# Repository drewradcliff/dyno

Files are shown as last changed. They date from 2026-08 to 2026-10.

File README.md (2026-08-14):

# Dyno

Dyno is an open-source finger-strength dynamometer. The project combines a
custom load-cell PCB, firmware for a Seeed Studio XIAO ESP32C3, and a mobile
app that displays force measurements over Bluetooth Low Energy.

## Repository

- [`hardware/`](hardware/) — KiCad schematic, PCB, and project-local libraries
- [`firmware/`](firmware/) — ESP32C3 firmware, calibration, and telemetry
- [`mobile/`](mobile/) — Expo/React Native companion app

The project is under active development. The PCB is currently an unverified
prototype and should be reviewed before fabrication.

## License

Original project work is licensed under the [MIT License](LICENSE). Third-party
components retain their upstream licenses and are attributed in the relevant
component directories.

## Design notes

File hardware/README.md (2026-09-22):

# Dyno hardware

KiCad design for the battery-powered Dyno finger-strength sensor. The board
combines a Seeed Studio XIAO ESP32C3 with an HX711 ADC and an external load
cell.

> **Status:** early, unverified prototype. The schematic and PCB have not yet
> been validated on manufactured hardware.

The [`production`](production) directory contains the JLCPCB Gerbers, BOM, and
placement data generated by KiCad's Fabrication Toolkit.

## Open the project

Open [`dyno.kicad_pro`](dyno.kicad_pro) with KiCad 10 or newer.

## Attribution and licensing

The original Dyno hardware design is licensed under the repository's
[MIT License](../LICENSE).

The vendored Seeed Studio XIAO KiCad libraries were created by Seeed Studio and
community contributors and are licensed separately under CC BY-SA 4.0. See
[`libraries/README.md`](libraries/README.md) and
[`libraries/LICENSE-CC-BY-SA-4.0.md`](libraries/LICENSE-CC-BY-SA-4.0.md).

The design also uses symbols and footprints from the official KiCad libraries,
which are distributed under CC BY-SA 4.0 with the KiCad libraries exception.
That exception permits their use in electronic designs without requiring the
design itself to adopt CC BY-SA.

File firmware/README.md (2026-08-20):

# Dyno firmware

Arduino firmware for the Seeed Studio XIAO ESP32C3. It reads an HX711 load-cell
ADC, calculates force, detects completed efforts, and publishes measurements
over serial and Bluetooth Low Energy.

## Setup

Install the ESP32 Arduino core and the
[HX711 library by bogde](https://github.com/bogde/HX711), then open
[`dyno/dyno.ino`](dyno/dyno.ino) in the Arduino IDE.

The HX711 connections expected by the firmware are:

- `D1`: active-low sleep/wake button
- `D3`: active-high status LED
- `D4`: HX711 `DOUT`
- `D5`: HX711 `PD_SCK`

The status LED is off while the dyno is idle, solid while an effort is active,
and blinks every 500 ms if the HX711 is not detected at startup.

## Sleep and wake button

The schematic's R2 pulls XIAO `D1` (GPIO 3) high, and SW1 connects it to ground
when pressed. Hold SW1 for two seconds and then release it to enter deep sleep.
Releasing before sleep prevents the active-low wake source from immediately
waking the board again. Press SW1 once while the board is asleep to wake it.

After a button wake, the firmware waits for SW1 to be released before arming
the hold-to-sleep behavior. This prevents a long wake press from creating a
sleep/wake loop. Deep sleep can also be requested with the `sleep` serial or
BLE command; if SW1 is held, sleep begins when it is released.

## BLE

The XIAO advertises as `Dyno` with an open GATT service. Connecting does not
require pairing or bonding.

| Item | UUID | Properties | Value |
| --- | --- | --- | --- |
| Dyno service | `7b7e1000-6ba3-4d8f-9e2f-4f2f0c7a0000` | — | — |
| Force | `7b7e1001-6ba3-4d8f-9e2f-4f2f0c7a0000` | Read, Notify | UTF-8 newtons with three decimal places, such as `12.345` |
| Command | `7b7e1002-6ba3-4d8f-9e2f-4f2f0c7a0000` | Write, Write Without Response | UTF-8 command, with or without a trailing newline |

Force notifications contain the latest filtered reading and are limited to
40 updates per second.

## Serial output

Open the serial port at 115200 baud. Each available HX711 conversion is read
once, timestamped, low-pass filtered, and emitted as CSV:

```csv
timestamp_ms,raw,force_newtons
1250,25802,0.406
1263,26143,8.104
1275,26994,27.314
```

Lines beginning with `#` are status messages or effort events. The `raw`
column is the unmodified HX711 reading; `force_newtons` is calculated from the
tared, filtered reading.

## Tare and calibration

At startup, the device collects 16 unloaded samples to establish its tare.
Keep the load cell unloaded until `# tare_complete` appears. Available serial
commands are:

```text
tare
factor 1461.258
calibrate 98.0665
thresholds 20 10 1000
last
status
sleep
help
```

- `tare` starts a fresh 16-sample unloaded tare.
- `factor <counts_per_newton>` sets the signed calibration factor.
- `calibrate <known_newtons>` calculates the factor from the currently applied
  force after an unloaded tare.
- `thresholds <start_n> <end_n> <hold_ms>` configures effort detection. The
  start threshold must be greater than the end threshold.
- `last` reports the most recently completed effort.
- `status` reports calibration, effort state, peak, and thresholds.
- `sleep` enters deep sleep with SW1 on `D1` configured as the active-low wake
  source.

Calibration and threshold settings persist in ESP32 flash. The default factor
converts the initial bench calibration of 6500 counts per pound-force:

```text
6500 counts/lbf / 4.448221615 N/lbf = 1461.258 counts/N
```

A negative calibration factor is valid when the raw reading falls as force is
applied.

## Efforts and peak force

An effort begins when filtered force rises above 20 N. The firmware tracks its
peak and ends it after force remains below 10 N for one second. This hysteresis
prevents small fluctuations from prematurely ending an effort.

Every completed effort records its ID, timestamps, duration, and peak force.
The last result remains available through `last` until restart. Taring,
calibrating, or changing thresholds during an effort cancels that partial
effort.

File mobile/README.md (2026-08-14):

# Dyno mobile

Expo/React Native companion app for the Dyno force sensor. It discovers the
device over Bluetooth Low Energy, reconnects to known devices, and displays
live force measurements.

## Development

```bash
npm install
npx expo run:ios
```

Use `npx expo run:android` for Android. BLE requires a development build and a
physical device; it is not available in Expo Go or a typical simulator.

After installing the development build, start Metro with:

```bash
npm start
```

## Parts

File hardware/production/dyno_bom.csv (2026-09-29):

Designator | Footprint | Quantity | Value | LCSC Part #
C1, C2, C5, C6, C7 | 0603 | 5 | 100n | C14663
C3, C4 | 0805 | 2 | 10u | C15850
D1 | 0603 | 1 | LED | C2286
J1 | JST_PH_S2B-PH-SM4-TB_1x02-1MP_P2.00mm_Horizontal | 1 | Battery | C295747
J2 | JST_SH_SM04B-SRSS-TB_1x04-1MP_P1.00mm_Horizontal | 1 | Load cell (4-wire) | C160404
Q1 | SOT-23 | 1 | MMBT3906LT1G | C53444
R1 | 0603 | 1 | 100k | C25803
R2, R4 | 0603 | 2 | 10k | C25804
R3 | 0603 | 1 | 14k | C22803
R5, R6 | 0603 | 2 | 100 | C22775
R7 | 0603 | 1 | 2.2k | C4190
SW1 | SW_SPST_B3U-1000P | 1 | B3U-1000P | C231329
U1 | XIAO-ESP32-C3-SMD | 1 | XIAO-ESP32-C3-SMD | C18212168
U2 | SOIC-16_3.9x9.9mm_P1.27mm | 1 | HX711 | C6705483

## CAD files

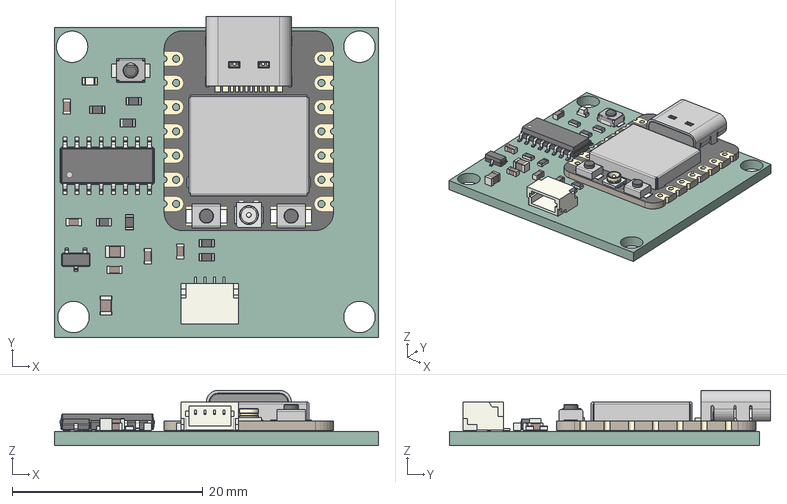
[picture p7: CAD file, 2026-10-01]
hardware/dyno-fusion-usb.step
34.0 x 33.7 x 5.80 mm
R_0603_1608Metric x 7
LED_0603_1608Metric
C_0603_1608Metric x 5
C_0805_2012Metric x 2
SOIC-16_3.9x9.9mm_P1.27mm
BOSS-EXTRUDE14_8_
BOSS-EXTRUDE7_4_
BOSS-EXTRUDE7_3_
BOSS-EXTRUDE14_4_
BOSS-EXTRUDE14_2_
BOSS-EXTRUDE14_11_
BOSS-EXTRUDE7_7_
BOSS-EXTRUDE14_9_
BOSS-EXTRUDE14_3_
BOSS-EXTRUDE14_7_
MIRROR2
BOSS-EXTRUDE14_5_
BOSS-EXTRUDE14_12_
BOSS-EXTRUDE7_8_
BOSS-EXTRUDE7_1_
BOSS-EXTRUDE14_10_
BOSS-EXTRUDE7_9_
BOSS-EXTRUDE14_6_
BOSS-EXTRUDE14_1_
BOSS-EXTRUDE7_6_
BOSS-EXTRUDE7_2_
CUT-EXTRUDE5
BOSS-EXTRUDE7_5_
U.FL Connector v1
Button (1) x 2
Shield
JST_SH_SM04B-SRSS-TB_1x04-1MP_P1.00mm_Horizontal
SOT-23
SW_SPST_B3U-1000P
dyno_PCB

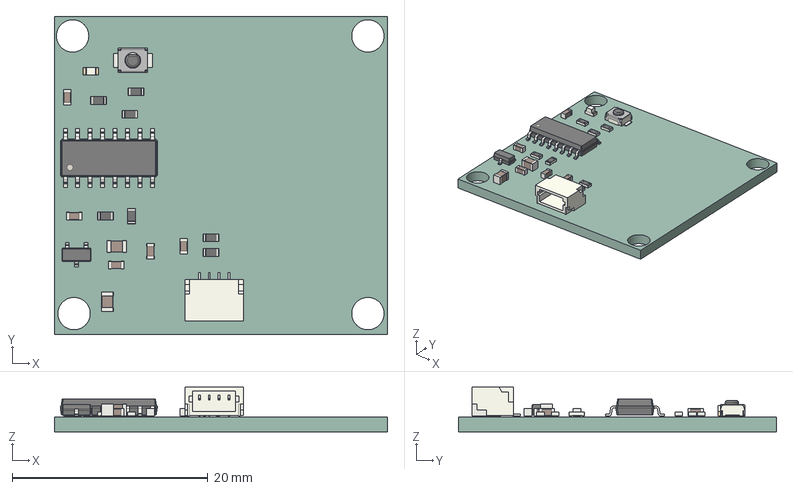
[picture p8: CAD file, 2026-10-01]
hardware/dyno-fusion.step
34.0 x 32.5 x 4.55 mm
R_0603_1608Metric x 7
LED_0603_1608Metric
C_0603_1608Metric x 5
C_0805_2012Metric x 2
SOIC-16_3.9x9.9mm_P1.27mm
JST_SH_SM04B-SRSS-TB_1x04-1MP_P1.00mm_Horizontal
SOT-23
SW_SPST_B3U-1000P
dyno-unsaved-export-k7dwvz_PCB

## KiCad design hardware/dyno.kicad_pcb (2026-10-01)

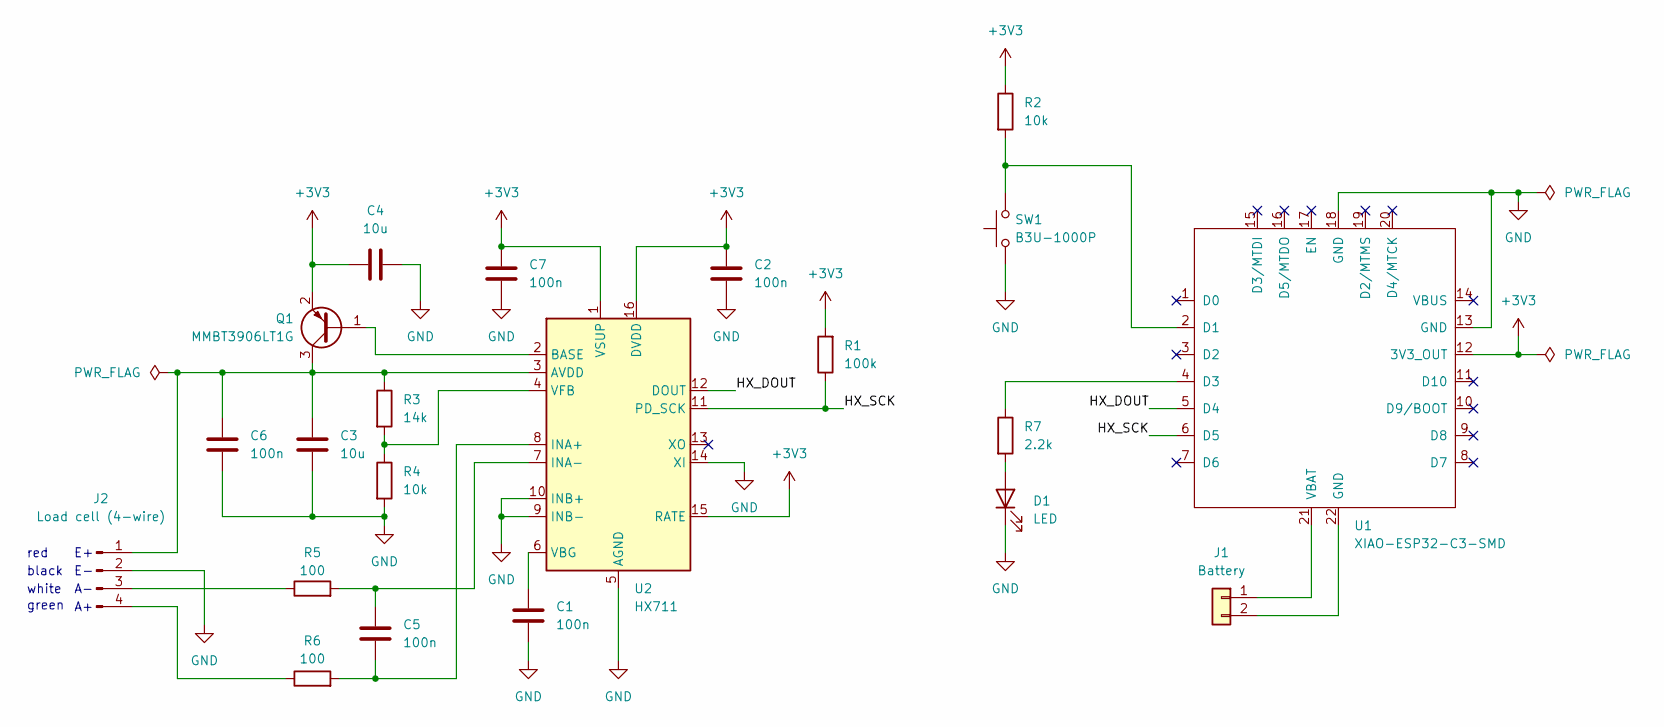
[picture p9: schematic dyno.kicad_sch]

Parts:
C1, C2, C5, C6, C7: 100n; C_0603_1608Metric; MPN CC0603KRX7R9BB104; JLCPCB Part # C14663
C3, C4: 10u; C_0805_2012Metric; MPN CL21A106KAYNNNE; JLCPCB Part # C15850
D1: LED; LED_0603_1608Metric; MPN KT-0603R; JLCPCB Part # C2286
J1: Battery; JST_PH_S2B-PH-SM4-TB_1x02-1MP_P2.00mm_Horizontal; MPN S2B-PH-SM4-TB(LF)(SN); JLCPCB Part # C295747
J2: Load cell (4-wire); JST_SH_SM04B-SRSS-TB_1x04-1MP_P1.00mm_Horizontal; MPN SM04B-SRSS-TB(LF)(SN); JLCPCB Part # C160404
Q1: MMBT3906LT1G; SOT-23; MPN MMBT3906LT1G; JLCPCB Part # C53444
R1: 100k; R_0603_1608Metric; MPN 0603WAF1003T5E; JLCPCB Part # C25803
R2, R4: 10k; R_0603_1608Metric; MPN 0603WAF1002T5E; JLCPCB Part # C25804
R3: 14k; R_0603_1608Metric; MPN 0603WAF1402T5E; JLCPCB Part # C22803
R5, R6: 100; R_0603_1608Metric; MPN 0603WAF1000T5E; JLCPCB Part # C22775
R7: 2.2k; R_0603_1608Metric; MPN 0603WAF2201T5E; JLCPCB Part # C4190
SW1: B3U-1000P; SW_SPST_B3U-1000P; MPN B3U-1000P; JLCPCB Part # C231329
U1: XIAO-ESP32-C3-SMD; MPN 113991054; JLCPCB Part # C18212168
U2: HX711; SOIC-16_3.9x9.9mm_P1.27mm; MPN HX711; JLCPCB Part # C6705483

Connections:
+3V3: C2.2, C4.1, C7.2, Q1.2 (E), R1.2, R2.1, U1.12 (3V3_OUT), U2.1 (VSUP), U2.15 (RATE), U2.16 (DVDD)
/HX_DOUT: U1.5 (D4), U2.12 (DOUT)
/HX_SCK: R1.1, U1.6 (D5), U2.11 (PD_SCK)
GND: C1.2, C2.1, C3.2, C4.2, C6.2, C7.1, D1.1 (K), J2.2, R4.2, SW1.1, U1.13 (GND), U1.18 (GND), U2.5 (AGND), U2.9 (INB-), U2.10 (INB+), U2.14 (XI)
unnamed: D1.2 (A), R7.2
unnamed: J1.1, U1.21 (VBAT)
unnamed: J1.2, U1.22 (GND)
unnamed: C3.1, C6.1, J2.1, Q1.3 (C), R3.1, U2.3 (AVDD)
unnamed: J2.3, R5.1
unnamed: J2.4, R6.1
unnamed: Q1.1 (B), U2.2 (BASE)
unnamed: R2.2, SW1.2, U1.2 (D1)
unnamed: R7.1, U1.4 (D3)
unnamed: C5.2, R6.2, U2.8 (INA+)
unnamed: C5.1, R5.2, U2.7 (INA-)
unnamed: C1.1, U2.6 (VBG)
unnamed: R3.2, R4.1, U2.4 (VFB)

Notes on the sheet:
green
red
white
black

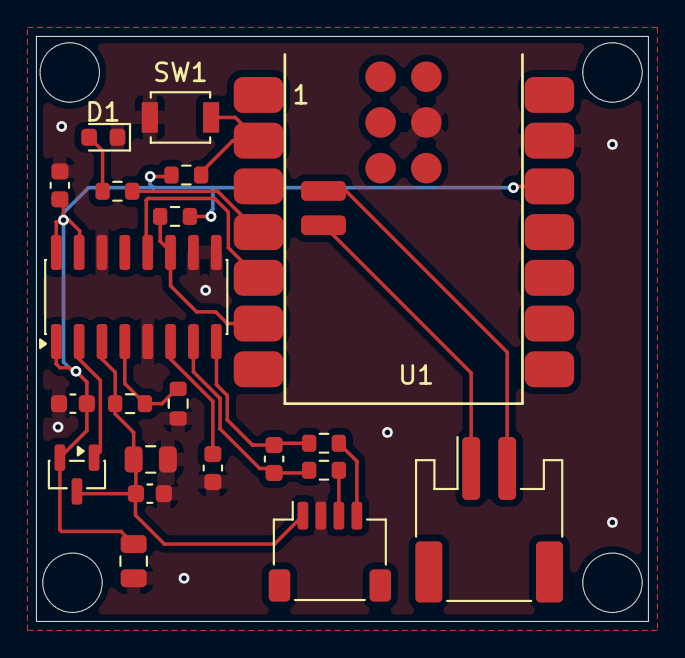
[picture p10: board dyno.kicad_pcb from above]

Board: 2 copper layers, 34.0 x 32.5 mm, 21 parts (0 on the bottom side), 17 nets.

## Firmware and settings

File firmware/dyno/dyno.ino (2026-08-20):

#include <Arduino.h>
#include <Preferences.h>
#include <esp_sleep.h>

#include <ctype.h>
#include <limits.h>
#include <math.h>
#include <stdlib.h>
#include <string.h>

#include "BleTelemetry.h"
#include "DynoTypes.h"
#include "EffortDetector.h"
#include "HX711.h"
#include "SerialTelemetry.h"

constexpr int HX711_DOUT_PIN = D4;
constexpr int HX711_SCK_PIN = D5;
constexpr int WAKE_BUTTON_PIN = D1;
constexpr int STATUS_LED_PIN = D3;

// R2 holds D1 high and SW1 pulls it low. Requiring a hold avoids putting the
// dyno to sleep during an accidental tap; sleep begins after the button is
// released so the same low level cannot immediately wake it again.
constexpr uint32_t WAKE_BUTTON_DEBOUNCE_MS = 30;
constexpr uint32_t WAKE_BUTTON_SLEEP_HOLD_MS = 2000;
constexpr uint32_t STATUS_LED_BLINK_INTERVAL_MS = 500;

// A positive factor means raw count rises with applied force. Use a negative
// factor if it falls. Serial calibration commands are persisted in flash.
constexpr float DEFAULT_CALIBRATION_FACTOR_COUNTS_PER_NEWTON = 1461.258f;
constexpr dyno::EffortConfig DEFAULT_EFFORT_CONFIG = {20.0f, 10.0f, 1000};

constexpr uint8_t TARE_SAMPLE_COUNT = 16;
constexpr float FILTER_ALPHA = 0.20f;
constexpr size_t COMMAND_BUFFER_SIZE = 96;

HX711 loadcell;
Preferences preferences;
SerialTelemetry serialTelemetry;
BleTelemetry bleTelemetry;
dyno::EffortDetector effortDetector(DEFAULT_EFFORT_CONFIG);

bool hx711Initialized = false;
bool hx711Detected = false;
bool preferencesReady = false;
bool statusError = false;
float calibrationFactor = DEFAULT_CALIBRATION_FACTOR_COUNTS_PER_NEWTON;
long tareOffset = 0;

bool tareInProgress = false;
uint8_t tareSamplesCollected = 0;
int64_t tareAccumulator = 0;

bool filterInitialized = false;
float filteredCounts = 0.0f;
bool hasMeasurement = false;
uint32_t nextSampleSequence = 0;

bool wakeButtonRawPressed = false;
bool wakeButtonStablePressed = false;
bool wakeButtonArmed = false;
bool sleepWhenWakeButtonReleased = false;
uint32_t wakeButtonRawChangedAtMs = 0;
uint32_t wakeButtonPressedAtMs = 0;

char commandBuffer[COMMAND_BUFFER_SIZE];
size_t commandLength = 0;
bool discardCommandUntilNewline = false;

void initializeStatusLed() {
  pinMode(STATUS_LED_PIN, OUTPUT);
  digitalWrite(STATUS_LED_PIN, LOW);
}

void updateStatusLed() {
  bool ledOn = effortDetector.active();
  if (statusError) {
    ledOn = (millis() / STATUS_LED_BLINK_INTERVAL_MS) % 2 == 0;
  }

  digitalWrite(STATUS_LED_PIN, ledOn ? HIGH : LOW);
}

void publishMeasurement(const dyno::ForceMeasurement &measurement) {
  serialTelemetry.publishMeasurement(measurement);
  bleTelemetry.publishMeasurement(measurement);
}

void publishEffortEvent(const dyno::EffortEvent &event) {
  serialTelemetry.publishEffortEvent(event);
}

void cancelActiveEffort() {
  publishEffortEvent(effortDetector.cancel(millis()));
}

void printWakeCause() {
  const esp_sleep_wakeup_cause_t wakeCause = esp_sleep_get_wakeup_cause();
  if (wakeCause == ESP_SLEEP_WAKEUP_GPIO) {
    Serial.println(F("# wake_cause=button"));
  } else {
    Serial.print(F("# wake_cause="));
    Serial.println(static_cast<int>(wakeCause));
  }
}

void enterDeepSleep() {
  cancelActiveEffort();
  digitalWrite(STATUS_LED_PIN, LOW);
  if (hx711Initialized) {
    loadcell.power_down();
  }
  if (preferencesReady) {
    preferences.end();
    preferencesReady = false;
  }

  const esp_err_t wakeResult = esp_deep_sleep_enable_gpio_wakeup(
      1ULL << WAKE_BUTTON_PIN, ESP_GPIO_WAKEUP_GPIO_LOW);
  if (wakeResult != ESP_OK) {
    Serial.print(F("# error,wake_button_config_failed="));
    Serial.println(esp_err_to_name(wakeResult));
    Serial.flush();
    delay(1000);
    ESP.restart();
  }

  Serial.println(F("# deep_sleep,wake_source=D1,active_level=low"));
  Serial.flush();
  delay(20);
  esp_deep_sleep_start();

  // esp_deep_sleep_start() does not return; keep the compiler aware of that.
  while (true) {
  }
}

void initializeWakeButton() {
  // The schematic includes an external 10 kOhm pull-up (R2). INPUT_PULLUP also
  // keeps the input defined if R2 is omitted during breadboard testing.
  pinMode(WAKE_BUTTON_PIN, INPUT_PULLUP);
  wakeButtonRawPressed = digitalRead(WAKE_BUTTON_PIN) == LOW;
  wakeButtonStablePressed = wakeButtonRawPressed;
  wakeButtonRawChangedAtMs = millis();
  wakeButtonPressedAtMs = millis();

  // A button still held after waking must be released before it can request
  // sleep. Otherwise a long wake press would cause a sleep/wake loop.
  wakeButtonArmed = !wakeButtonStablePressed;
}

void pollWakeButton() {
  const uint32_t nowMs = millis();
  const bool rawPressed = digitalRead(WAKE_BUTTON_PIN) == LOW;

  if (rawPressed != wakeButtonRawPressed) {
    wakeButtonRawPressed = rawPressed;
    wakeButtonRawChangedAtMs = nowMs;
  }

  if (wakeButtonStablePressed != wakeButtonRawPressed &&
      nowMs - wakeButtonRawChangedAtMs >= WAKE_BUTTON_DEBOUNCE_MS) {
    wakeButtonStablePressed = wakeButtonRawPressed;
    if (wakeButtonStablePressed) {
      if (wakeButtonArmed) {
        wakeButtonPressedAtMs = nowMs;
      }
    } else {
      wakeButtonArmed = true;
      if (sleepWhenWakeButtonReleased) {
        enterDeepSleep();
      }
    }
  }

  if (wakeButtonArmed && wakeButtonStablePressed &&
      !sleepWhenWakeButtonReleased &&
      nowMs - wakeButtonPressedAtMs >= WAKE_BUTTON_SLEEP_HOLD_MS) {
    sleepWhenWakeButtonReleased = true;
    Serial.println(F("# sleep_requested,release_button_to_sleep"));
  }
}

void beginTare() {
  cancelActiveEffort();
  tareInProgress = true;
  tareSamplesCollected = 0;
  tareAccumulator = 0;
  filterInitialized = false;
  hasMeasurement = false;
  Serial.println(F("# tare_start"));
}

void collectTareSample(long raw) {
  tareAccumulator += raw;
  ++tareSamplesCollected;

  if (tareSamplesCollected < TARE_SAMPLE_COUNT) {
    return;
  }

  tareOffset = static_cast<long>(tareAccumulator / TARE_SAMPLE_COUNT);
  tareInProgress = false;

  Serial.print(F("# tare_complete,offset="));
  Serial.println(tareOffset);
}

void persistCalibrationFactor() {
  if (preferencesReady) {
    preferences.putFloat("factor", calibrationFactor);
  }
}

void persistEffortConfig() {
  if (!preferencesReady) {
    return;
  }

  const dyno::EffortConfig &config = effortDetector.config();
  preferences.putFloat("start_n", config.startForceNewtons);
  preferences.putFloat("end_n", config.endForceNewtons);
  preferences.putUInt("hold_ms", config.endHoldMs);
}

void printCalibrationFactor() {
  Serial.print(F("# calibration_factor_counts_per_newton="));
  Serial.println(calibrationFactor, 6);
}

void printEffortConfig() {
  const dyno::EffortConfig &config = effortDetector.config();
  Serial.print(F("# effort_config,start_force_newtons="));
  Serial.print(config.startForceNewtons, 3);
  Serial.print(F(",end_force_newtons="));
  Serial.print(config.endForceNewtons, 3);
  Serial.print(F(",end_hold_ms="));
  Serial.println(config.endHoldMs);
}

void printHelp() {
  Serial.println(F("# commands: tare | factor <counts_per_newton> | calibrate <known_newtons> | thresholds <start_n> <end_n> <hold_ms> | last | status | sleep | help"));
}

void printLastEffort() {
  if (!effortDetector.hasLastCompletedEffort()) {
    Serial.println(F("# last_effort,none"));
    return;
  }

  serialTelemetry.publishLastEffort(effortDetector.lastCompletedEffort());
}

void printStatus() {
  const dyno::EffortConfig &config = effortDetector.config();
  Serial.print(F("# status,tare_offset="));
  Serial.print(tareOffset);
  Serial.print(F(",calibration_factor_counts_per_newton="));
  Serial.print(calibrationFactor, 6);
  Serial.print(F(",effort_active="));
  Serial.print(effortDetector.active() ? 1 : 0);
  Serial.print(F(",effort_id="));
  Serial.print(effortDetector.currentEffortId());
  Serial.print(F(",current_peak_force_newtons="));
  Serial.print(effortDetector.currentPeakForceNewtons(), 3);
  Serial.print(F(",start_force_newtons="));
  Serial.print(config.startForceNewtons, 3);
  Serial.print(F(",end_force_newtons="));
  Serial.print(config.endForceNewtons, 3);
  Serial.print(F(",end_hold_ms="));
  Serial.println(config.endHoldMs);
}

void skipWhitespace(const char *&cursor) {
  while (isspace(static_cast<unsigned char>(*cursor))) {
    ++cursor;
  }
}

bool parseFloatToken(const char *&cursor, float &value) {
  if (cursor == nullptr) {
    return false;
  }

  skipWhitespace(cursor);
  char *end = nullptr;
  value = strtof(cursor, &end);
  if (end == cursor || !isfinite(value)) {
    return false;
  }

  cursor = end;
  return true;
}

bool parseUInt32Token(const char *&cursor, uint32_t &value) {
  if (cursor == nullptr) {
    return false;
  }

  skipWhitespace(cursor);
  if (*cursor == '-') {
    return false;
  }

  char *end = nullptr;
  const unsigned long parsed = strtoul(cursor, &end, 10);
  if (end == cursor || parsed > UINT32_MAX) {
    return false;
  }

  value = static_cast<uint32_t>(parsed);
  cursor = end;
  return true;
}

bool isEndOfArguments(const char *cursor) {
  if (cursor == nullptr) {
    return true;
  }

  skipWhitespace(cursor);
  return *cursor == '\0';
}

bool parseSingleFloatArgument(const char *argument, float &value) {
  return parseFloatToken(argument, value) && isEndOfArguments(argument);
}

bool parseEffortConfig(const char *argument, dyno::EffortConfig &config) {
  return parseFloatToken(argument, config.startForceNewtons) &&
         parseFloatToken(argument, config.endForceNewtons) &&
         parseUInt32Token(argument, config.endHoldMs) &&
         isEndOfArguments(argument) &&
         dyno::EffortDetector::isValidConfig(config);
}

void applyCalibrationFactor(float newFactor) {
  cancelActiveEffort();
  calibrationFactor = newFactor;
  persistCalibrationFactor();
  printCalibrationFactor();
}

void applyEffortConfig(const dyno::EffortConfig &config) {
  cancelActiveEffort();
  effortDetector.setConfig(config);
  persistEffortConfig();
  printEffortConfig();
}

void handleCommand(char *command) {
  while (isspace(static_cast<unsigned char>(*command))) {
    ++command;
  }

  char *commandEnd = command + strlen(command);
  while (commandEnd > command &&
         isspace(static_cast<unsigned char>(commandEnd[-1]))) {
    --commandEnd;
  }
  *commandEnd = '\0';

  if (*command == '\0') {
    return;
  }

  char *argument = command;
  while (*argument != '\0' &&
         !isspace(static_cast<unsigned char>(*argument))) {
    ++argument;
  }
  if (*argument != '\0') {
    *argument = '\0';
    ++argument;
  } else {
    argument = nullptr;
  }

  if (strcmp(command, "tare") == 0) {
    if (!hx711Detected) {
      Serial.println(F("# error,hx711_not_detected"));
      return;
    }

    beginTare();
    return;
  }

  if (strcmp(command, "factor") == 0) {
    float requestedFactor = 0.0f;
    if (!parseSingleFloatArgument(argument, requestedFactor) ||
        fabsf(requestedFactor) < 0.000001f) {
      Serial.println(
          F("# error,usage=factor <non-zero counts_per_newton>"));
      return;
    }

    applyCalibrationFactor(requestedFactor);
    return;
  }

  if (strcmp(command, "calibrate") == 0) {
    float knownForceNewtons = 0.0f;
    if (!parseSingleFloatArgument(argument, knownForceNewtons) ||
        knownForceNewtons <= 0.0f) {
      Serial.println(
          F("# error,usage=calibrate <positive_known_newtons>"));
      return;
    }

    if (!hasMeasurement || fabsf(filteredCounts) < 1.0f) {
      Serial.println(F("# error,apply_known_force_before_calibrating"));
      return;
    }

    applyCalibrationFactor(filteredCounts / knownForceNewtons);
    return;
  }

  if (strcmp(command, "thresholds") == 0) {
    dyno::EffortConfig config = DEFAULT_EFFORT_CONFIG;
    if (!parseEffortConfig(argument, config)) {
      Serial.println(
          F("# error,usage=thresholds <start_n> <end_n> <hold_ms>; start_n must be greater than end_n"));
      return;
    }

    applyEffortConfig(config);
    return;
  }

  if (strcmp(command, "last") == 0) {
    printLastEffort();
    return;
  }

  if (strcmp(command, "status") == 0) {
    printStatus();
    return;
  }

  if (strcmp(command, "sleep") == 0) {
    if (digitalRead(WAKE_BUTTON_PIN) == LOW) {
      sleepWhenWakeButtonReleased = true;
      Serial.println(F("# sleep_requested,release_button_to_sleep"));
    } else {
      enterDeepSleep();
    }
    return;
  }

  if (strcmp(command, "help") == 0) {
    printHelp();
    return;
  }

  Serial.println(F("# error,unknown_command"));
  printHelp();
}

void readSerialCommands() {
  while (Serial.available() > 0) {
    const char nextCharacter = static_cast<char>(Serial.read());

    if (nextCharacter == '\r') {
      continue;
    }

    if (nextCharacter == '\n') {
      if (discardCommandUntilNewline) {
        discardCommandUntilNewline = false;
        commandLength = 0;
        continue;
      }

      commandBuffer[commandLength] = '\0';
      handleCommand(commandBuffer);
      commandLength = 0;
      continue;
    }

    if (discardCommandUntilNewline) {
      continue;
    }

    if (commandLength < COMMAND_BUFFER_SIZE - 1) {
      commandBuffer[commandLength++] = nextCharacter;
    } else {
      commandLength = 0;
      discardCommandUntilNewline = true;
      Serial.println(F("# error,command_too_long"));
    }
  }
}

void readBleCommands() {
  char command[COMMAND_BUFFER_SIZE];
  if (bleTelemetry.takeCommand(command, sizeof(command))) {
    handleCommand(command);
  }
}

void processSample(long raw, uint32_t timestampMs) {
  const float netCounts = static_cast<float>(raw - tareOffset);

  if (!filterInitialized) {
    filteredCounts = netCounts;
    filterInitialized = true;
  } else {
    filteredCounts += FILTER_ALPHA * (netCounts - filteredCounts);
  }

  hasMeasurement = true;
  const float forceNewtons = filteredCounts / calibrationFactor;
  publishEffortEvent(effortDetector.update(forceNewtons, timestampMs));

  const dyno::ForceMeasurement measurement = {
      nextSampleSequence++,
      timestampMs,
      static_cast<int32_t>(raw),
      forceNewtons,
      effortDetector.currentEffortId(),
      effortDetector.active(),
  };
  publishMeasurement(measurement);
}

void loadPersistentSettings() {
  preferencesReady = preferences.begin("dyno", false);
  if (!preferencesReady) {
    return;
  }

  const float storedFactor = preferences.getFloat(
      "factor", DEFAULT_CALIBRATION_FACTOR_COUNTS_PER_NEWTON);
  if (isfinite(storedFactor) && fabsf(storedFactor) >= 0.000001f) {
    calibrationFactor = storedFactor;
  }

  dyno::EffortConfig storedConfig = {
      preferences.getFloat("start_n",
                           DEFAULT_EFFORT_CONFIG.startForceNewtons),
      preferences.getFloat("end_n", DEFAULT_EFFORT_CONFIG.endForceNewtons),
      preferences.getUInt("hold_ms", DEFAULT_EFFORT_CONFIG.endHoldMs),
  };
  effortDetector.setConfig(storedConfig);
}

void setup() {
  initializeStatusLed();
  initializeWakeButton();
  Serial.begin(115200);
  delay(1500);

  Serial.println(F("# dyno_starting"));
  printWakeCause();
  bleTelemetry.begin();

  loadcell.begin(HX711_DOUT_PIN, HX711_SCK_PIN);
  hx711Initialized = true;
  loadcell.power_up();
  if (!loadcell.wait_ready_timeout(2000)) {
    statusError = true;
    Serial.println(F("# error,hx711_not_detected"));
    printHelp();
    return;
  }

  hx711Detected = true;
  loadPersistentSettings();
  printCalibrationFactor();
  printEffortConfig();
  printHelp();
  serialTelemetry.printHeader();
  beginTare();
}

void loop() {
  updateStatusLed();
  pollWakeButton();
  bleTelemetry.poll();
  readSerialCommands();
  readBleCommands();

  if (!hx711Detected || !loadcell.is_ready()) {
    delay(1);
    return;
  }

  // Consume every conversion once. Filtering happens after the individual raw
  // sample is read, so 80 SPS operation retains its time resolution.
  const long raw = loadcell.read();
  const uint32_t timestampMs = millis();

  if (tareInProgress) {
    collectTareSample(raw);
    return;
  }

  processSample(raw, timestampMs);
}

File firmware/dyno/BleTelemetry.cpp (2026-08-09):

#include "BleTelemetry.h"

#include <BLE2902.h>
#include <BLEAdvertising.h>
#include <BLECharacteristic.h>
#include <BLEDevice.h>
#include <BLEServer.h>
#include <BLEService.h>

#include <stdio.h>
#include <string.h>

const char *const BleTelemetry::DEVICE_NAME = "Dyno";
const char *const BleTelemetry::SERVICE_UUID =
    "7b7e1000-6ba3-4d8f-9e2f-4f2f0c7a0000";
const char *const BleTelemetry::FORCE_CHARACTERISTIC_UUID =
    "7b7e1001-6ba3-4d8f-9e2f-4f2f0c7a0000";
const char *const BleTelemetry::COMMAND_CHARACTERISTIC_UUID =
    "7b7e1002-6ba3-4d8f-9e2f-4f2f0c7a0000";

class DynoBleServerCallbacks : public BLEServerCallbacks {
 public:
  explicit DynoBleServerCallbacks(BleTelemetry &telemetry)
      : telemetry_(telemetry) {}

  void onConnect(BLEServer *) override { telemetry_.onConnect(); }

  void onDisconnect(BLEServer *) override { telemetry_.onDisconnect(); }

 private:
  BleTelemetry &telemetry_;
};

class DynoBleCommandCallbacks : public BLECharacteristicCallbacks {
 public:
  explicit DynoBleCommandCallbacks(BleTelemetry &telemetry)
      : telemetry_(telemetry) {}

  void onWrite(BLECharacteristic *characteristic) override {
    const auto value = characteristic->getValue();
    telemetry_.queueCommand(value.c_str(), value.length());
  }

 private:
  BleTelemetry &telemetry_;
};

BleTelemetry::BleTelemetry()
    : server_(nullptr),
      forceCharacteristic_(nullptr),
      connected_(false),
      advertisingRestartPending_(false),
      disconnectedAtMs_(0),
      connectedEventPending_(false),
      disconnectedEventPending_(false),
      commandTooLongEventPending_(false),
      commandQueueFullEventPending_(false),
      hasNotificationTimestamp_(false),
      lastNotificationTimestampMs_(0),
      commandPending_(false),
      pendingCommandLength_(0),
      pendingCommand_{} {}

void BleTelemetry::begin() {
  // No security callbacks or encrypted properties are configured: clients can
  // connect and use this debugging service without pairing or bonding.
  BLEDevice::init(DEVICE_NAME);

  server_ = BLEDevice::createServer();
  server_->setCallbacks(new DynoBleServerCallbacks(*this));

  BLEService *service = server_->createService(SERVICE_UUID);
  forceCharacteristic_ = service->createCharacteristic(
      FORCE_CHARACTERISTIC_UUID,
      BLECharacteristic::PROPERTY_READ | BLECharacteristic::PROPERTY_NOTIFY);
  forceCharacteristic_->setValue("0.000");
  forceCharacteristic_->addDescriptor(new BLE2902());

  BLECharacteristic *commandCharacteristic = service->createCharacteristic(
      COMMAND_CHARACTERISTIC_UUID,
      BLECharacteristic::PROPERTY_WRITE |
          BLECharacteristic::PROPERTY_WRITE_NR);
  commandCharacteristic->setCallbacks(new DynoBleCommandCallbacks(*this));

  service->start();

  BLEAdvertising *advertising = BLEDevice::getAdvertising();
  advertising->addServiceUUID(SERVICE_UUID);
  advertising->setScanResponse(true);
  advertising->setMinPreferred(0x06);
  advertising->setMaxPreferred(0x12);
  BLEDevice::startAdvertising();

  Serial.print(F("# ble_advertising,device_name="));
  Serial.print(DEVICE_NAME);
  Serial.print(F(",service_uuid="));
  Serial.println(SERVICE_UUID);
}

void BleTelemetry::poll() {
  bool shouldRestartAdvertising = false;
  bool connectedEvent = false;
  bool disconnectedEvent = false;
  bool commandTooLongEvent = false;
  bool commandQueueFullEvent = false;

  portENTER_CRITICAL(&stateMux_);
  if (advertisingRestartPending_ &&
      millis() - disconnectedAtMs_ >= ADVERTISING_RESTART_DELAY_MS) {
    advertisingRestartPending_ = false;
    shouldRestartAdvertising = true;
  }
  connectedEvent = connectedEventPending_;
  disconnectedEvent = disconnectedEventPending_;
  commandTooLongEvent = commandTooLongEventPending_;
  commandQueueFullEvent = commandQueueFullEventPending_;
  connectedEventPending_ = false;
  disconnectedEventPending_ = false;
  commandTooLongEventPending_ = false;
  commandQueueFullEventPending_ = false;
  portEXIT_CRITICAL(&stateMux_);

  if (connectedEvent) {
    Serial.println(F("# ble_connected"));
  }
  if (disconnectedEvent) {
    Serial.println(F("# ble_disconnected"));
  }
  if (commandTooLongEvent) {
    Serial.println(F("# error,ble_command_too_long"));
  }
  if (commandQueueFullEvent) {
    Serial.println(F("# error,ble_command_queue_full"));
  }
  if (shouldRestartAdvertising) {
    BLEDevice::startAdvertising();
    Serial.println(F("# ble_advertising_restarted"));
  }
}

void BleTelemetry::publishMeasurement(
    const dyno::ForceMeasurement &measurement) {
  if (forceCharacteristic_ == nullptr) {
    return;
  }

  bool shouldNotify = false;
  portENTER_CRITICAL(&stateMux_);
  if (connected_ &&
      (!hasNotificationTimestamp_ ||
       measurement.timestampMs - lastNotificationTimestampMs_ >=
           NOTIFICATION_INTERVAL_MS)) {
    hasNotificationTimestamp_ = true;
    lastNotificationTimestampMs_ = measurement.timestampMs;
    shouldNotify = true;
  }
  portEXIT_CRITICAL(&stateMux_);

  if (!shouldNotify) {
    return;
  }

  char forceText[24];
  const int length =
      snprintf(forceText, sizeof(forceText), "%.3f", measurement.forceNewtons);
  if (length <= 0) {
    return;
  }

  const size_t valueLength =
      static_cast<size_t>(length) < sizeof(forceText)
          ? static_cast<size_t>(length)
          : sizeof(forceText) - 1;
  forceCharacteristic_->setValue(
      reinterpret_cast<const uint8_t *>(forceText), valueLength);
  forceCharacteristic_->notify();
}

bool BleTelemetry::takeCommand(char *destination, size_t destinationSize) {
  if (destination == nullptr || destinationSize == 0) {
    return false;
  }

  bool hasCommand = false;
  portENTER_CRITICAL(&stateMux_);
  if (commandPending_) {
    const size_t copyLength =
        pendingCommandLength_ < destinationSize - 1
            ? pendingCommandLength_
            : destinationSize - 1;
    memcpy(destination, pendingCommand_, copyLength);
    destination[copyLength] = '\0';
    commandPending_ = false;
    pendingCommandLength_ = 0;
    hasCommand = true;
  }
  portEXIT_CRITICAL(&stateMux_);

  return hasCommand;
}

void BleTelemetry::onConnect() {
  portENTER_CRITICAL(&stateMux_);
  connected_ = true;
  advertisingRestartPending_ = false;
  connectedEventPending_ = true;
  hasNotificationTimestamp_ = false;
  portEXIT_CRITICAL(&stateMux_);
}

void BleTelemetry::onDisconnect() {
  portENTER_CRITICAL(&stateMux_);
  connected_ = false;
  advertisingRestartPending_ = true;
  disconnectedAtMs_ = millis();
  disconnectedEventPending_ = true;
  hasNotificationTimestamp_ = false;
  portEXIT_CRITICAL(&stateMux_);
}
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

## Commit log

2026-08-10 Add BLE device scanning interface and build profiles
2026-08-10 Add dyno device connection controls and persistence
2026-08-14 Document project structure and mobile development setup
    [dyno.kicad_pcb, dyno.kicad_sch]
2026-08-16 wire mcu and amp
    [dyno.kicad_sch]
2026-08-16 handle sleep/wake button
2026-08-16 fix ERC errors
    [dyno.kicad_sch]
2026-08-19 clean up schematic
    [dyno.kicad_sch]
2026-08-20 add status LED
    [dyno.kicad_sch]
2026-09-22 Prepare hardware prototype for JLCPCB assembly
    [dyno.kicad_pcb, dyno_bom.csv, dyno_designators.csv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]
2026-09-29 Correct XIAO part number for JLCPCB
    [dyno.kicad_pcb, dyno.kicad_sch, dyno_bom.csv]
2026-10-01 export CAD model
    [dyno-fusion-usb.step, dyno-fusion.step, dyno.kicad_pcb]
